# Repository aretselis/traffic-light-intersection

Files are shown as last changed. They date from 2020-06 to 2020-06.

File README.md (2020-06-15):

# Traffic Light Intersection

An Arduino based traffic light project for the class HTE501 (Electronics Circuits Laboratory) at the Physics Department of the Aristotle University of Thessaloniki.

Inside this repository readers can find:

- The fritzing schematic file `Traffic_light_intersection.fzz`
- The code for Arduino `traffic_lights.ino`

## Current Circuit Schematic

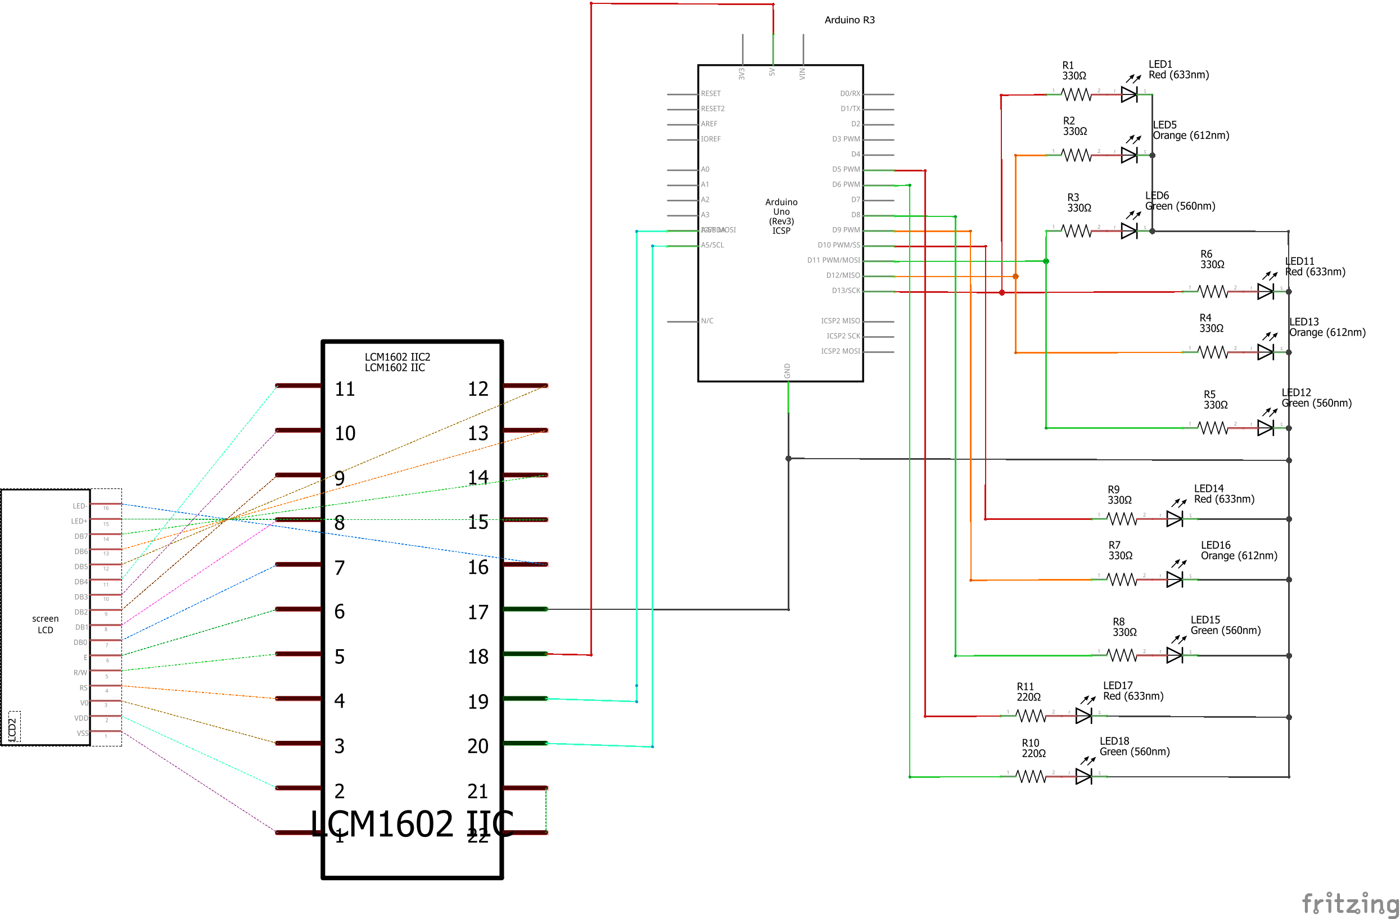
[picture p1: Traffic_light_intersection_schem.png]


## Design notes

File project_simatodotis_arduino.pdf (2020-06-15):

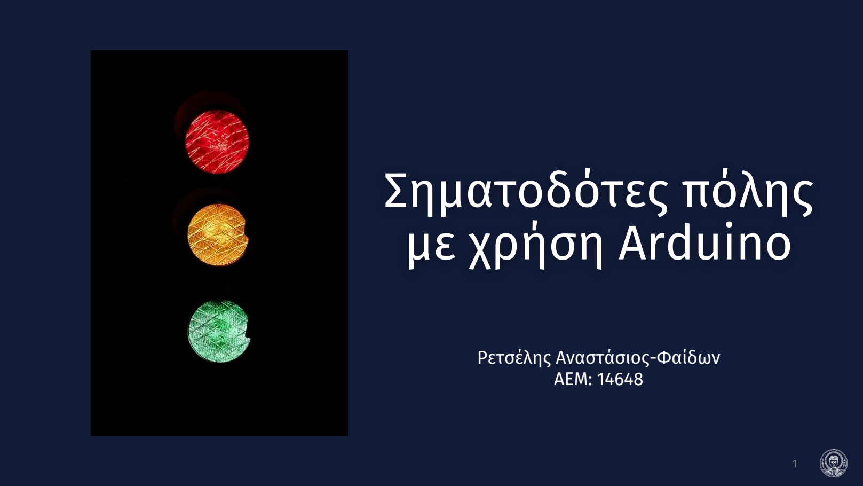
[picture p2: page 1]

# Σηματοδότες πόλης με χρήση Arduino

Ρετσέλης Αναστάσιος-Φαίδων ΑΕΜ: 14648

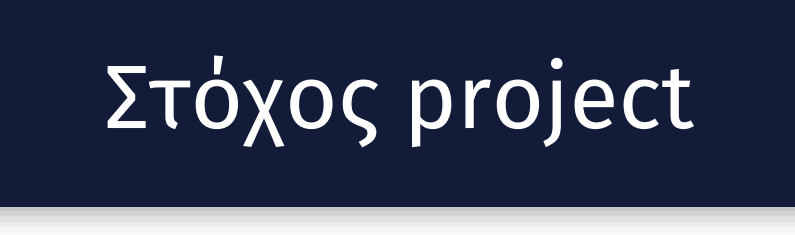
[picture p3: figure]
Στόχος project

## H ρεαλιστική αναπαράσταση μιας τυπικής διασταύρωσης με τη χρήση του μικροελεγκτή Arduino

## H διασταύρωση (Αδριανουπόλεως-Αιγαίου)

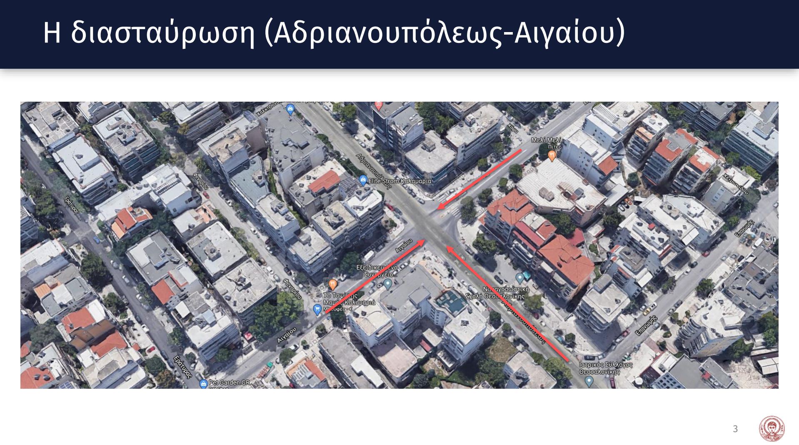
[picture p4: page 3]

## H διασταύρωση (Αδριανουπόλεως-Αιγαίου)

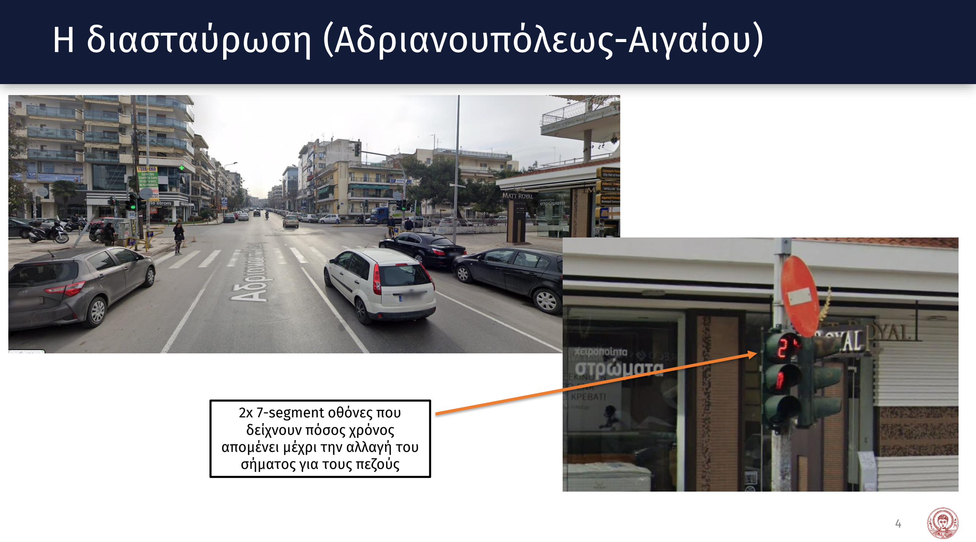
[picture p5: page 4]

2x 7-segment οθόνες που
δείχνουν πόσος χρόνος
απομένει μέχρι την αλλαγή του σήματος για τους πεζούς

## Οθόνες 7-τμημάτων (7-segment displays)

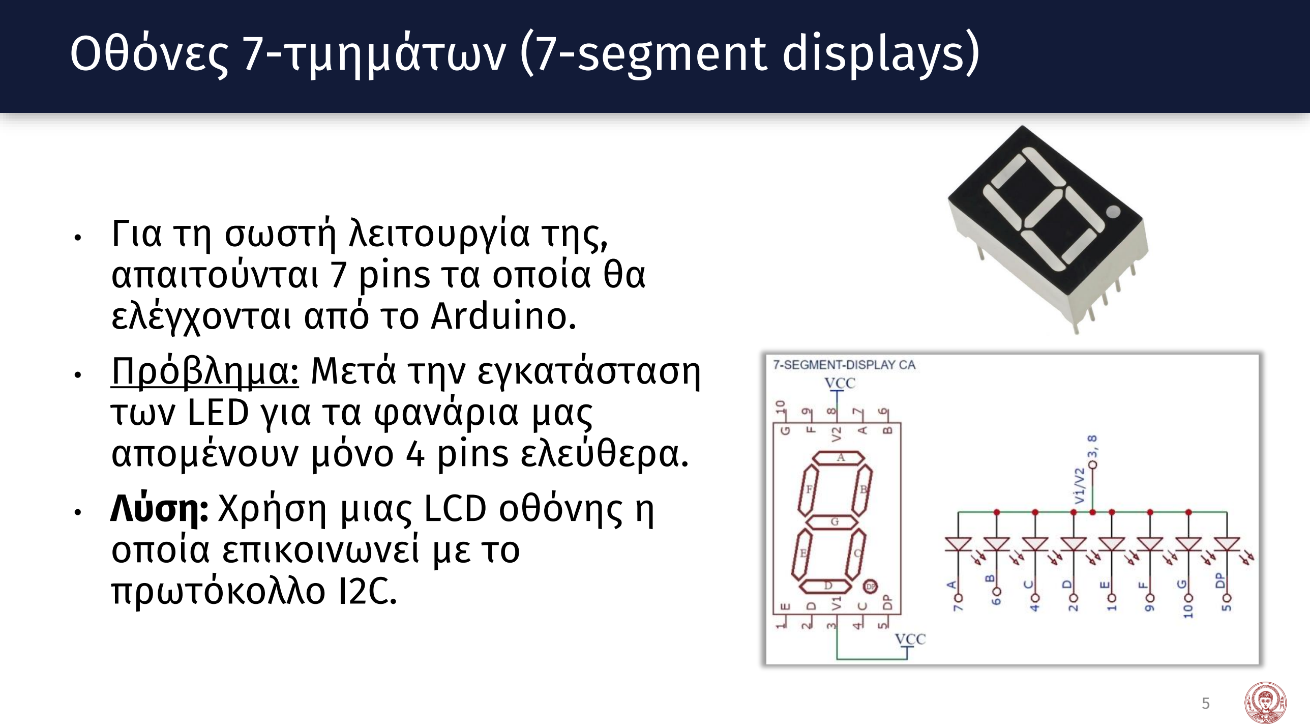
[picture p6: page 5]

- Για τη σωστή λειτουργία της, απαιτούνται 7 pins τα οποία θα ελέγχονται από το Arduino.
- Πρόβλημα: Μετά την εγκατάσταση των LED για τα φανάρια μας απομένουν μόνο 4 pins ελεύθερα.
- Λύση: Χρήση μιας LCD οθόνης η οποία επικοινωνεί με το
πρωτόκολλο I2C.

## Λίστα υλικών

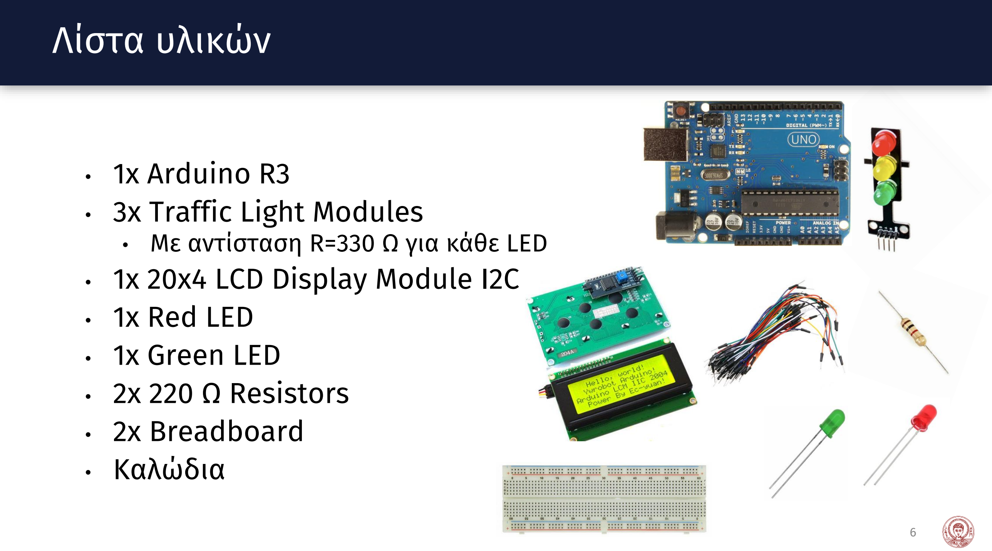
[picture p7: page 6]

- 1x Arduino R3
- 3x Traffic Light Modules
- Με αντίσταση R=330 Ω για κάθε LED
- 1x 20x4 LCD Display Module I2C
- 1x Red LED
- 1x Green LED
- 2x 220 Ω Resistors
- 2x Breadboard
- Καλώδια

## Σχηματικό κυκλώματος

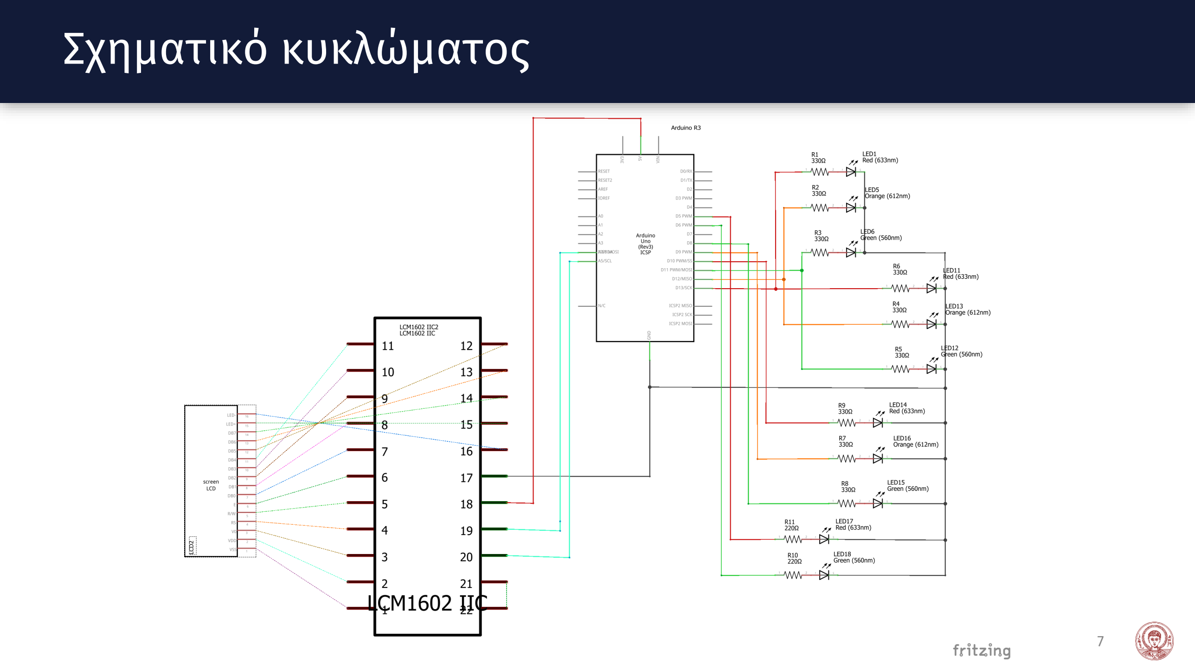
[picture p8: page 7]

## Σχηματικό κυκλώματος

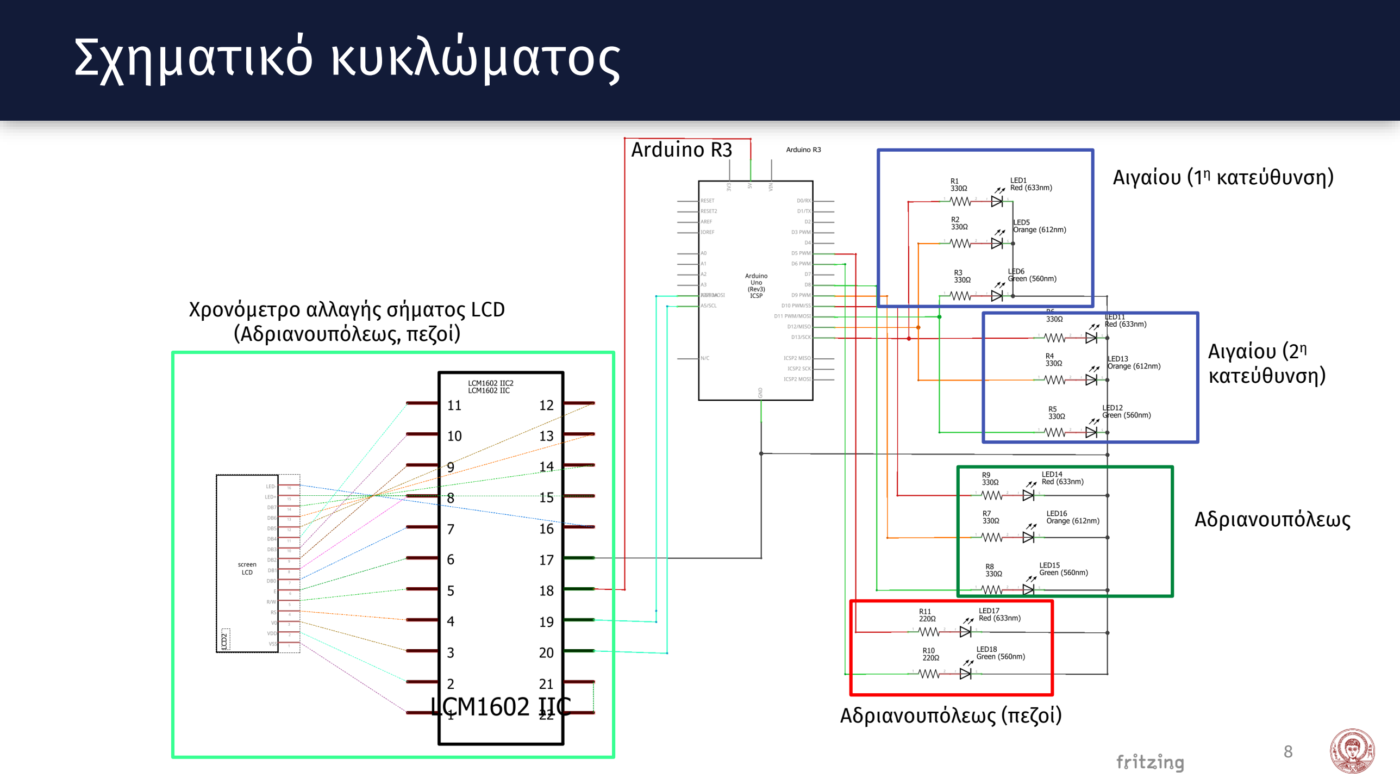
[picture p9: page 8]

Αιγαίου (1η κατεύθυνση)

Αιγαίου (2
η
κατεύθυνση)

Αδριανουπόλεως

Αδριανουπόλεως (πεζοί)

Χρονόμετρο αλλαγής σήματος LCD (Αδριανουπόλεως, πεζοί)

Arduino R3

## Η κατασκευή

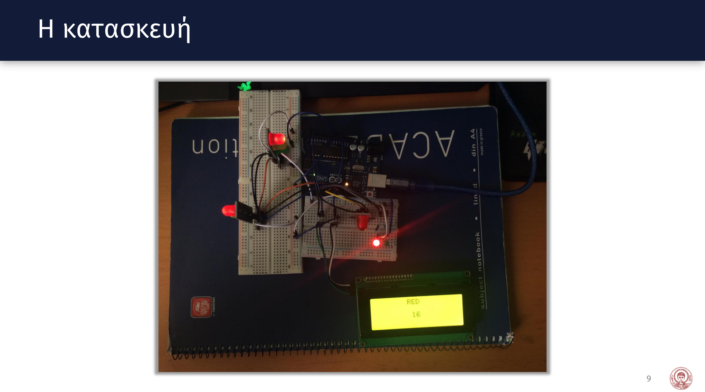
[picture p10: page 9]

## Η κατασκευή

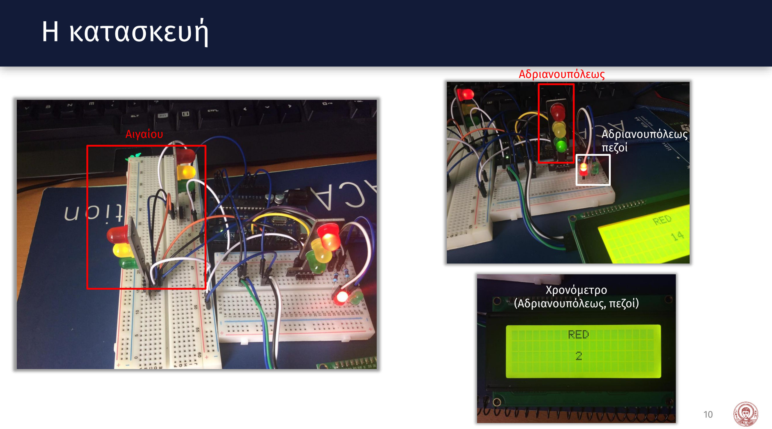
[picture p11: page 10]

Αιγαίου

Αδριανουπόλεως

Αδριανουπόλεως
πεζοί

Χρονόμετρο
(Αδριανουπόλεως, πεζοί)

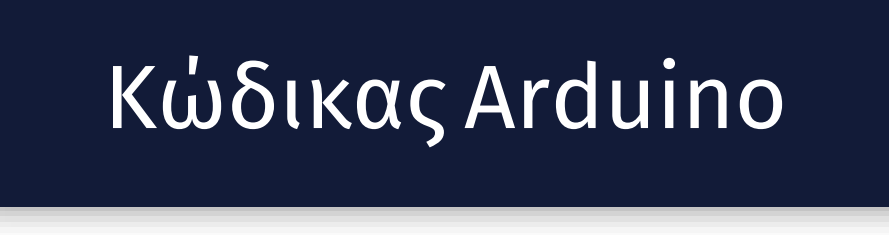
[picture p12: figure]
Κώδικας Arduino

- Βασικές απαιτήσεις από τον κώδικα:
❑ Εύκολη ρύθμιση της διάρκειας κάθε εναλλαγής (για άμεση αλλαγή από την τροχαία εάν απαιτείται)
❑ Χρήση ίδιων pins για την οδό Αιγαίου ώστε να εξοικονομηθούν 3 pins
❑ Μη στιγμιαία εναλλαγή σήματος αυτοκινήτων μετά από την εναλλαγή σε κόκκινο για τους πεζούς, ώστε να έχουν οι πεζοί χρόνο να διασχίσουν την οδό με ασφάλεια
❑ Ένδειξη του χρόνου μέχρι την αλλαγή σήματος για τους πεζού στην LCD οθόνη
❑ Χρήση συναρτήσεων για εύκολες μελλοντικές τροποποιήσεις (π.χ. να ανάβει πορτοκαλί και πριν την αλλαγή από κόκκινο σε πράσινο, όπως συμβαίνει σε πολλές χώρες του εξωτερικού)

## Ορισμός pins και setup του Arduino

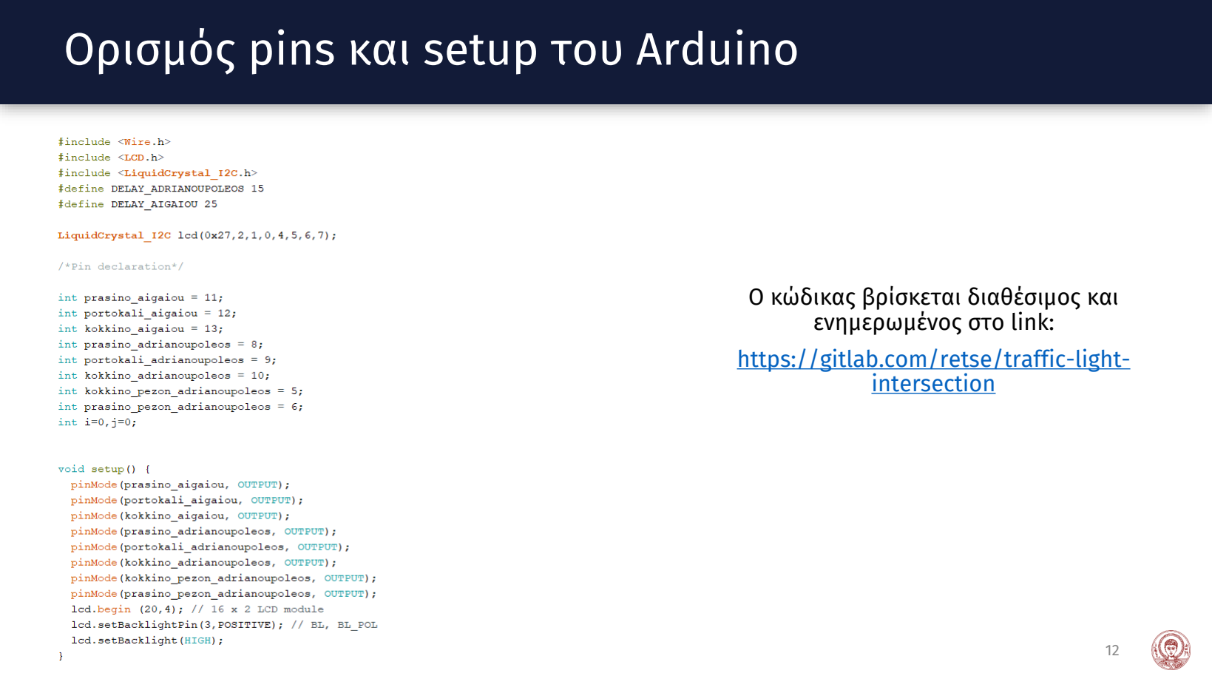
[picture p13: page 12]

Ο κώδικας βρίσκεται διαθέσιμος και ενημερωμένος στο link:
https://gitlab.com/retse/traffic-lightintersection (https://gitlab.com/retse/traffic-light-intersection)

Ο κώδικας βρίσκεται διαθέσιμος και ενημερωμένος στο link:
https://gitlab.com/retse/traffic-lightintersection (https://gitlab.com/retse/traffic-light-intersection)

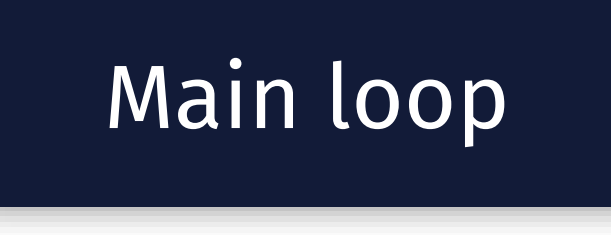
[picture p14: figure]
Main loop

## Συνάρτηση adrianoupoleos_sequence()

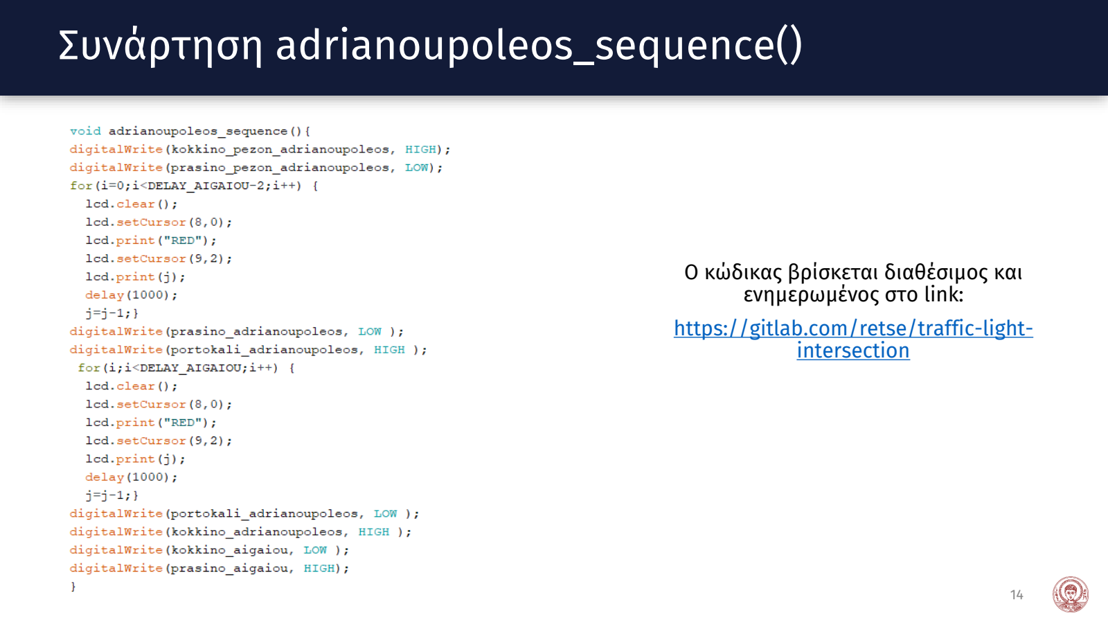
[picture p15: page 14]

Ο κώδικας βρίσκεται διαθέσιμος και ενημερωμένος στο link:
https://gitlab.com/retse/traffic-lightintersection (https://gitlab.com/retse/traffic-light-intersection)

## Συνάρτηση aigaiou_sequence()

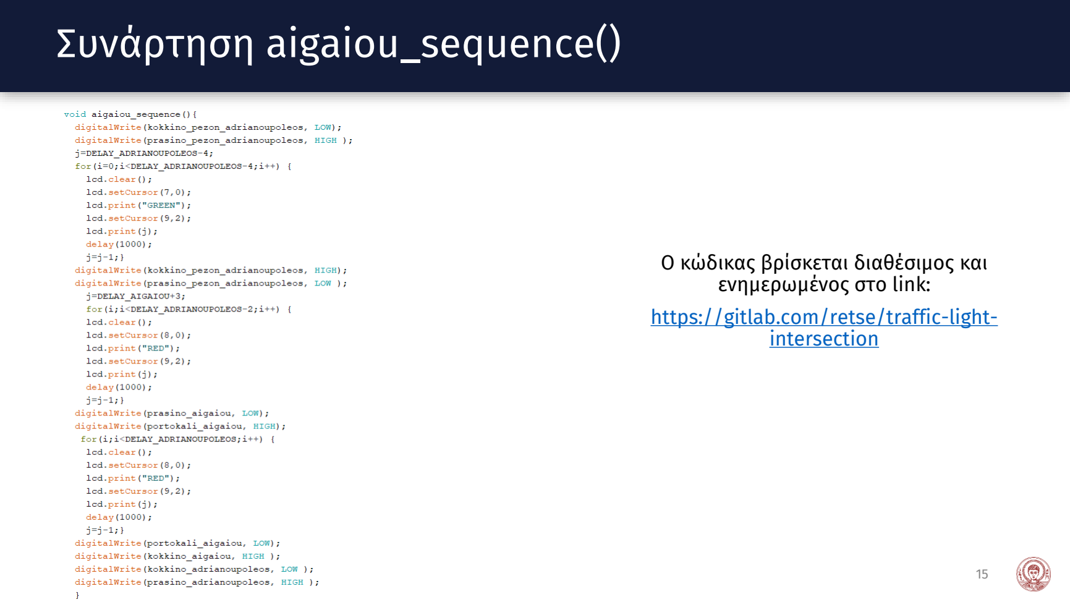
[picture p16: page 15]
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

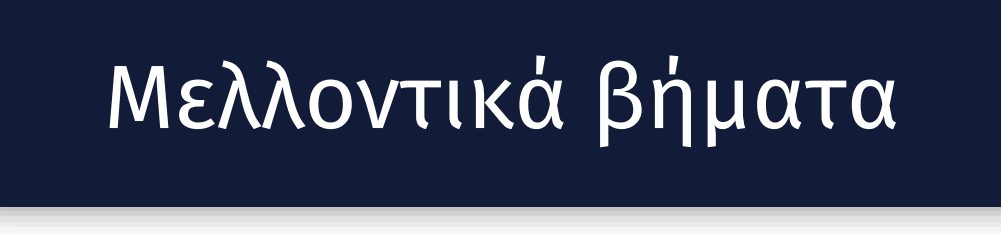
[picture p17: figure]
Μελλοντικά βήματα

- Χρήση ηχείου για προειδοποίηση τυφλών
- Προσθήκη του σηματοδότη για τους πεζούς στην Αιγαίου
- Δυνατότητα αλλαγής της διάρκειας του πράσινου σήματος για τα αυτοκίνητα:
❑ Μέσω διαδικτύου (από το κέντρο της διεύθυνσης τροχαίας)
❑ Ανάλογα τη χρονική στιγμή της ημέρας
- Επέκταση δυνατοτήτων για 1, 2 ή 4 κατευθύνσεις

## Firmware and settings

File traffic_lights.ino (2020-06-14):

#include <Wire.h> 
#include <LCD.h>
#include <LiquidCrystal_I2C.h>
#define DELAY_ADRIANOUPOLEOS 15
#define DELAY_AIGAIOU 25

LiquidCrystal_I2C lcd(0x27,2,1,0,4,5,6,7);

/*Pin declaration*/

int prasino_aigaiou = 11;
int portokali_aigaiou = 12;
int kokkino_aigaiou = 13;
int prasino_adrianoupoleos = 8;
int portokali_adrianoupoleos = 9;
int kokkino_adrianoupoleos = 10;
int kokkino_pezon_adrianoupoleos = 5;
int prasino_pezon_adrianoupoleos = 6;
int i=0,j=0;


void setup() {
  pinMode(prasino_aigaiou, OUTPUT);
  pinMode(portokali_aigaiou, OUTPUT);
  pinMode(kokkino_aigaiou, OUTPUT);
  pinMode(prasino_adrianoupoleos, OUTPUT);
  pinMode(portokali_adrianoupoleos, OUTPUT);
  pinMode(kokkino_adrianoupoleos, OUTPUT);
  pinMode(kokkino_pezon_adrianoupoleos, OUTPUT);
  pinMode(prasino_pezon_adrianoupoleos, OUTPUT);
  lcd.begin (20,4); // 16 x 2 LCD module
  lcd.setBacklightPin(3,POSITIVE); // BL, BL_POL
  lcd.setBacklight(HIGH);   
  digitalWrite(prasino_aigaiou, LOW);
  digitalWrite(portokali_aigaiou, LOW);
  digitalWrite(kokkino_aigaiou, HIGH );
  digitalWrite(prasino_adrianoupoleos, HIGH );
}


void loop() {
  j=DELAY_AIGAIOU-1;
  adrianoupoleos_sequence();
  aigaiou_sequence();
}

void aigaiou_sequence(){
  digitalWrite(kokkino_pezon_adrianoupoleos, LOW);
  digitalWrite(prasino_pezon_adrianoupoleos, HIGH );
  j=DELAY_ADRIANOUPOLEOS-4;
  for(i=0;i<DELAY_ADRIANOUPOLEOS-4;i++) {
    lcd.clear();
    lcd.setCursor(7,0);
    lcd.print("GREEN");
    lcd.setCursor(9,2);
    lcd.print(j);
    delay(1000);
    j=j-1;}
  digitalWrite(kokkino_pezon_adrianoupoleos, HIGH);
  digitalWrite(prasino_pezon_adrianoupoleos, LOW );
    j=DELAY_AIGAIOU+3;
    for(i;i<DELAY_ADRIANOUPOLEOS-2;i++) {
    lcd.clear();
    lcd.setCursor(8,0);
    lcd.print("RED");
    lcd.setCursor(9,2);
    lcd.print(j);
    delay(1000);
    j=j-1;}
  digitalWrite(prasino_aigaiou, LOW);
  digitalWrite(portokali_aigaiou, HIGH);
   for(i;i<DELAY_ADRIANOUPOLEOS;i++) {
    lcd.clear();
    lcd.setCursor(8,0);
    lcd.print("RED");
    lcd.setCursor(9,2);
    lcd.print(j);
    delay(1000);
    j=j-1;}
  digitalWrite(portokali_aigaiou, LOW);
  digitalWrite(kokkino_aigaiou, HIGH );
  digitalWrite(kokkino_adrianoupoleos, LOW );
  digitalWrite(prasino_adrianoupoleos, HIGH );
  }

  void adrianoupoleos_sequence(){
  digitalWrite(kokkino_pezon_adrianoupoleos, HIGH);
  digitalWrite(prasino_pezon_adrianoupoleos, LOW);
  for(i=0;i<DELAY_AIGAIOU-2;i++) {
    lcd.clear();
    lcd.setCursor(8,0);
    lcd.print("RED");
    lcd.setCursor(9,2);
    lcd.print(j);
    delay(1000);
    j=j-1;}
  digitalWrite(prasino_adrianoupoleos, LOW );
  digitalWrite(portokali_adrianoupoleos, HIGH );
   for(i;i<DELAY_AIGAIOU;i++) {
    lcd.clear();
    lcd.setCursor(8,0);
    lcd.print("RED");
    lcd.setCursor(9,2);
    lcd.print(j);
    delay(1000);
    j=j-1;}
  digitalWrite(portokali_adrianoupoleos, LOW );
  digitalWrite(kokkino_adrianoupoleos, HIGH );
  digitalWrite(kokkino_aigaiou, LOW );
  digitalWrite(prasino_aigaiou, HIGH);
  }

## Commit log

2020-06-14 Upload fritzing schematic
    [Traffic_light_intersection.fzz]
2020-06-14 Upload Schematic Picture
2020-06-14 Upload Arduino Code
2020-06-14 Improve modularity and fix formatting
    [traffic_lights.ino]
